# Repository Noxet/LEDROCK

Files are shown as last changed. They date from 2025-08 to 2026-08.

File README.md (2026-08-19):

# LEDROCK

LEDROCK is a custom controller for the IKEA LEDBERG RGB LED strip, built around an ESP32.

The project replaces the original LEDBERG controller and adds multiple ways of controlling the strip. It can be controlled over Wi-Fi using WebSockets, or directly over a serial connection using a custom command protocol.

A desktop light-bar application can capture the colors along the lower edge of the PC display and reproduce them on the LED strip, turning it into a lightweight screen-reactive ambient lighting system.

The repository contains the complete project, including:

- ESP32 firmware - LED control, WebSocket interface, and serial command protocol
- Custom controller hardware
- Desktop light-bar application - mirrors colors from the lower portion of the display
- Command-line application - direct control of the LED strip over USB-C

The project combines custom hardware, embedded firmware, networking, serial communication, and desktop software into a complete LED control system.

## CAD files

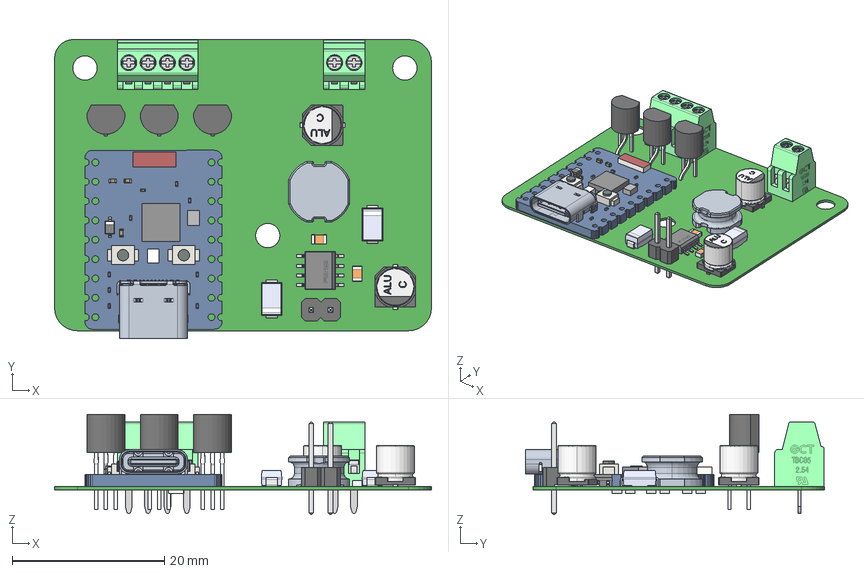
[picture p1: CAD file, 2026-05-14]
hardware/Ledrock/Manufacturing/ExportSTEP/Ledrock.step
49.5 x 39.3 x 13.2 mm
User Library-DO-214AC_SMA x 2
BOARD
USER_LIBRARY-RES_0603-0201_1 x 9
USER_LIBRARY-RES_0603-0201_2 x 9
USER_LIBRARY-RES_0603-0201_3 x 9
USER_LIBRARY-RES_0603-0201_4 x 9
EXTRUDED-29178
2_A x 13
EXTRUDED-51780
EXTRUDED-52493 x 2
SOD323
3_1_A x 3
CORE
CA-C03
User Library-TPS54360DDA
User Library-R_0805 x 6
User Library-Pin Header Strip
srn8040-150m
Fuss_1 x 2
Pins_1 x 2
Korper_1 x 2
Beschriftnug_1 x 2
User Library-C0805-2 x 2

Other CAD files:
hardware/Ledrock/Manufacturing/AutoCAD PCB/Ledrock.DXF
hardware/Ledrock/Manufacturing/AutoCAD PCB/Ledrock.DWG

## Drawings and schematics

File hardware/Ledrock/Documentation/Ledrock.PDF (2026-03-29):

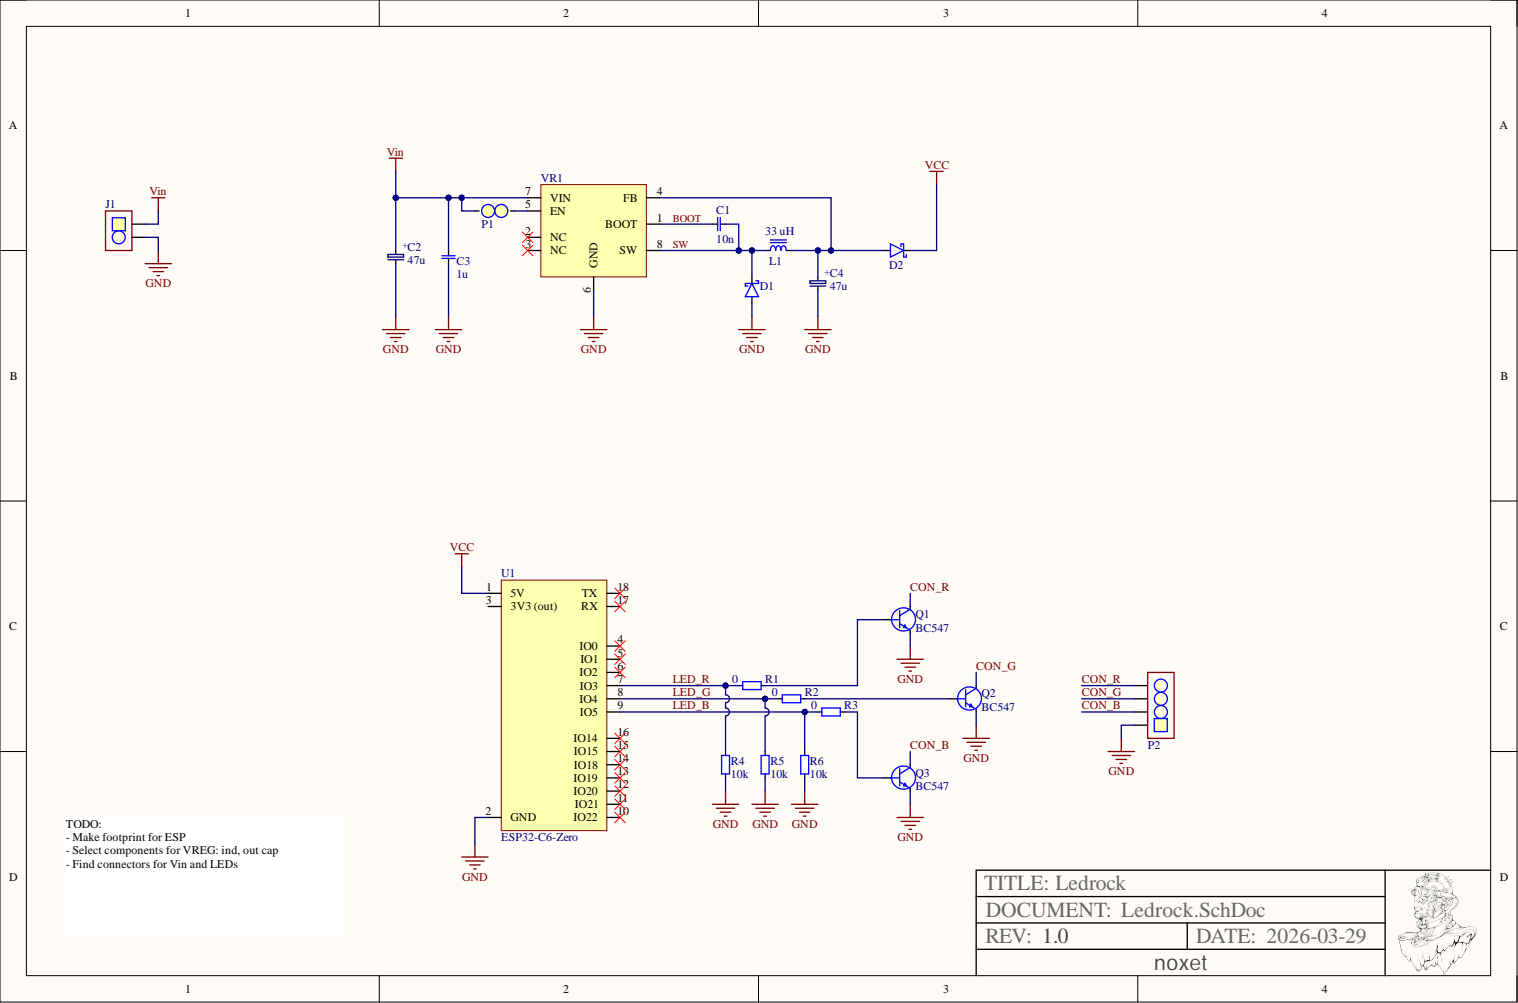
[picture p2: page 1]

TODO:
- Make footprint for ESP
- Select components for VREG: ind, out cap
- Find connectors for Vin and LEDs

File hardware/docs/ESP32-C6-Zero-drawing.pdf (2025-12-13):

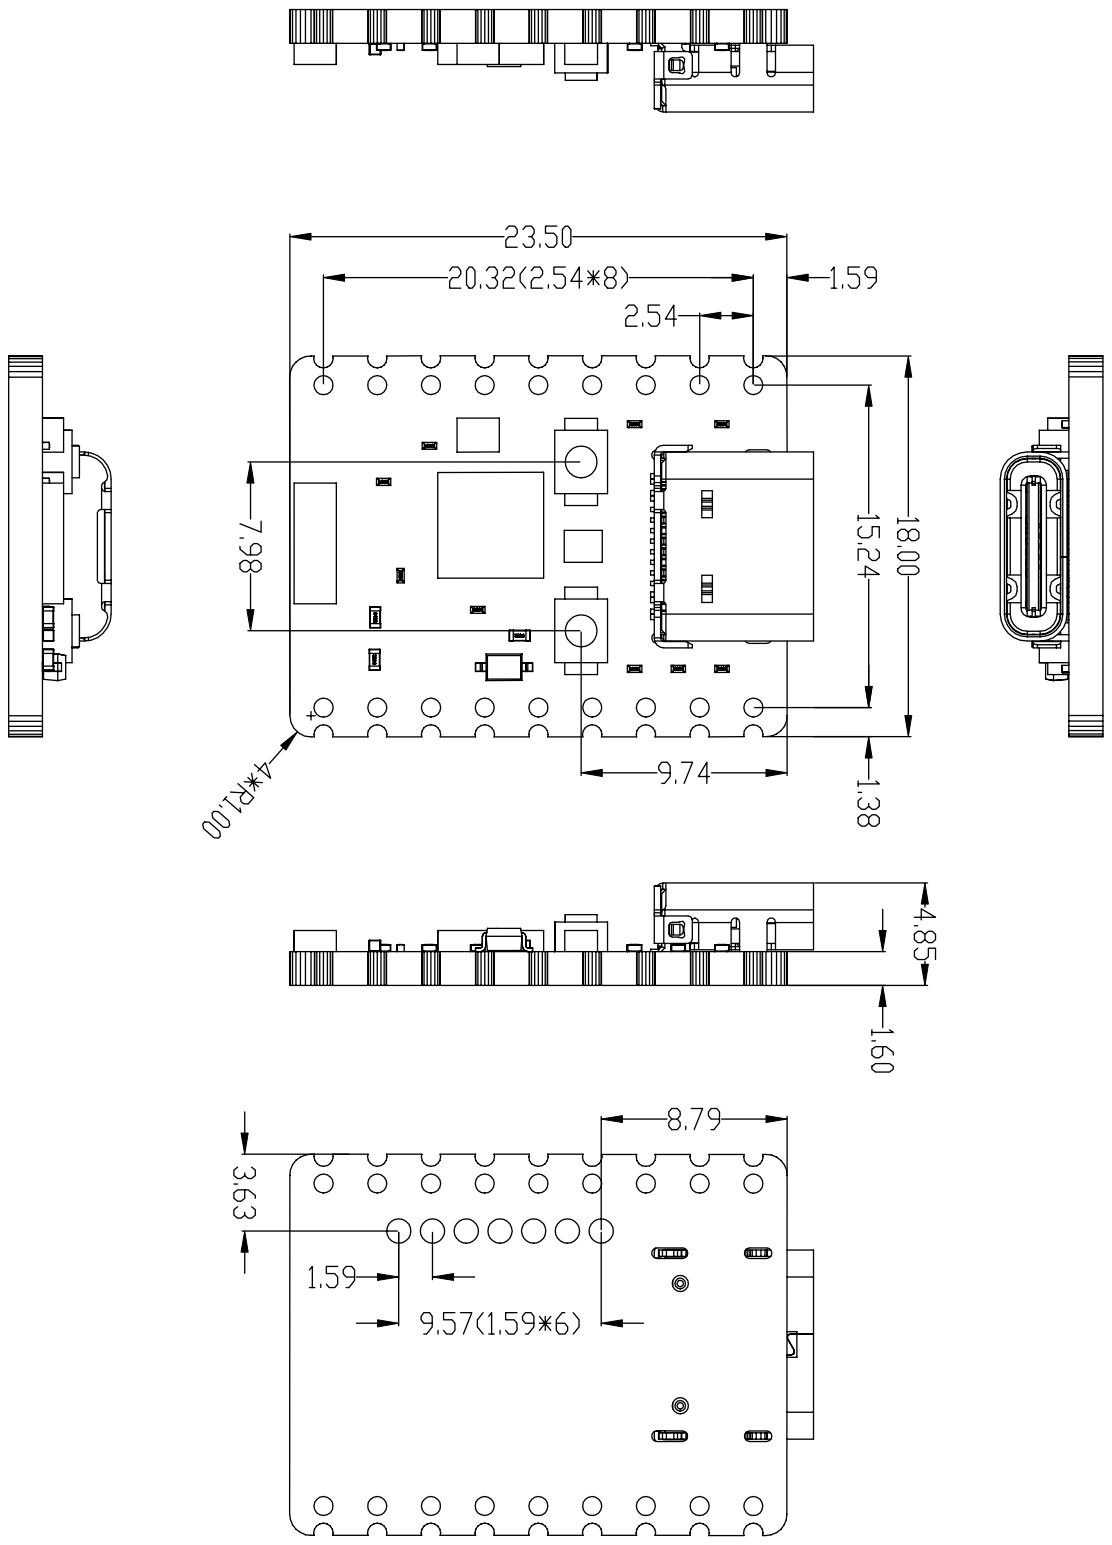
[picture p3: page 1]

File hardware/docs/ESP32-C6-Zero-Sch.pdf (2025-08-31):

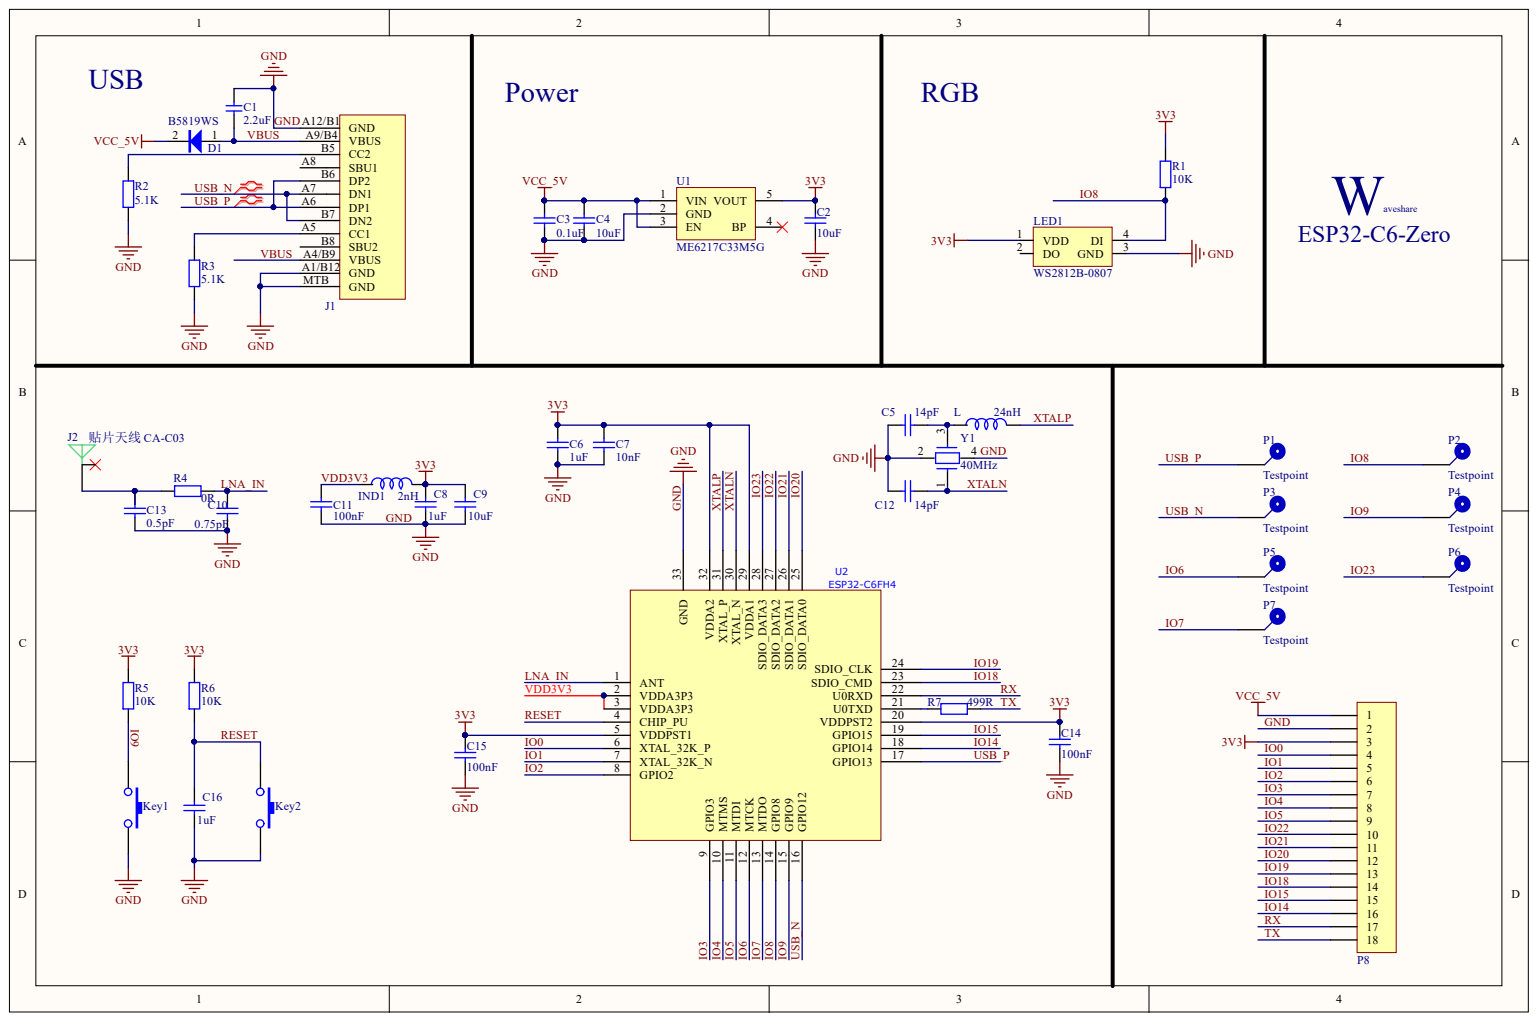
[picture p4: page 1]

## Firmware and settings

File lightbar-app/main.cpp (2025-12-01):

#include <Windows.h>
#include <dxgi1_2.h>
#include <d3d11.h>
#include <wrl.h>
#include <iostream>
#include <cstdint>

using Microsoft::WRL::ComPtr;

HANDLE serialOpen(const std::string &port, DWORD baud = CBR_115200)
{
	HANDLE handle = CreateFileA(
	    port.c_str(),
	    GENERIC_READ | GENERIC_WRITE,
	    0,
	    nullptr,
	    OPEN_EXISTING,
	    FILE_ATTRIBUTE_NORMAL,
	    nullptr
	    );

	if (handle == INVALID_HANDLE_VALUE)
	{
		std::cerr << "Failed to open " << port << "\n";
		return nullptr;
	}

	DCB dcb = { 0 };
	dcb.DCBlength = sizeof(dcb);

	if (!GetCommState(handle, &dcb)) {
		std::cerr << "GetCommState failed\n";
		CloseHandle(handle);
		return nullptr;
	}

	dcb.BaudRate = baud;
	dcb.ByteSize = 8;
	dcb.StopBits = ONESTOPBIT;
	dcb.Parity   = NOPARITY;
	dcb.fDtrControl = DTR_CONTROL_ENABLE;

	if (!SetCommState(handle, &dcb)) {
		std::cerr << "SetCommState failed\n";
		CloseHandle(handle);
		return nullptr;
	}

	// Timeout settings (non-blocking)
	/*
	COMMTIMEOUTS timeouts = { 0 };
	timeouts.ReadIntervalTimeout = 50;
	timeouts.ReadTotalTimeoutConstant = 50;
	timeouts.ReadTotalTimeoutMultiplier = 10;
	timeouts.WriteTotalTimeoutConstant = 10;
	 */

	//SetCommTimeouts(handle, &timeouts);

	return handle;
}

bool serialWrite(HANDLE handle, const uint8_t *data, int len)
{
	DWORD written;
	uint8_t msg[5];
	msg[0] = 0x04;
	msg[1] = 0x01; // static color
	memcpy(&msg[2], data, 3);
	// clean any leftover data in the software buffer. The latest data is more important
	PurgeComm(handle, PURGE_TXCLEAR);
	FlushFileBuffers(handle);
	if (!WriteFile(handle, msg, sizeof(msg), &written, nullptr)) return false;
	return written == sizeof(msg);
}

int main()
{
	HANDLE serial = serialOpen(R"(\\.\COM10)");
	if (!serial)
	{
		std::cerr << "Failed to open serial port\n";
		return EXIT_FAILURE;
	}

	HRESULT hr;

	// Create D3D11 device
	ComPtr<ID3D11Device> device;
	ComPtr<ID3D11DeviceContext> ctx;

	hr = D3D11CreateDevice(
	    nullptr,
	    D3D_DRIVER_TYPE_HARDWARE,
	    nullptr,
	    D3D11_CREATE_DEVICE_BGRA_SUPPORT,
	    nullptr, 0,
	    D3D11_SDK_VERSION,
	    &device,
	    nullptr,
	    &ctx);

	if (FAILED(hr)) {
		std::cout << "D3D11CreateDevice failed\n";
		return -1;
	}

	ComPtr<IDXGIDevice> dxgiDevice;
	device.As(&dxgiDevice);

	// Get primary output
	ComPtr<IDXGIAdapter> adapter;
	dxgiDevice->GetAdapter(&adapter);

	ComPtr<IDXGIOutput> output;
	adapter->EnumOutputs(0, &output);

	ComPtr<IDXGIOutput1> output1;
	output.As(&output1);

	// Create duplication
	ComPtr<IDXGIOutputDuplication> dup;
	hr = output1->DuplicateOutput(device.Get(), &dup);
	if (FAILED(hr)) {
		std::cout << "DuplicateOutput failed\n";
		return -2;
	}

	DXGI_OUTDUPL_DESC desc;
	dup->GetDesc(&desc);

	UINT W = desc.ModeDesc.Width;
	UINT H = desc.ModeDesc.Height;

	// We only want bottom N rows:
	const UINT NUM_ROWS = 300;

	// Create staging texture for bottom rows only
	D3D11_TEXTURE2D_DESC stagingDesc = {};
	stagingDesc.Width = W;
	stagingDesc.Height = NUM_ROWS;
	stagingDesc.MipLevels = 1;
	stagingDesc.ArraySize = 1;
	stagingDesc.Format = DXGI_FORMAT_B8G8R8A8_UNORM;
	stagingDesc.SampleDesc.Count = 1;
	stagingDesc.Usage = D3D11_USAGE_STAGING;
	stagingDesc.CPUAccessFlags = D3D11_CPU_ACCESS_READ;

	ComPtr<ID3D11Texture2D> staging;
	device->CreateTexture2D(&stagingDesc, nullptr, &staging);

	// Capture loop
	while (true)
	{
		DXGI_OUTDUPL_FRAME_INFO info = {};
		ComPtr<IDXGIResource> frameRes;

		hr = dup->AcquireNextFrame(5, &info, &frameRes);
		if (hr == DXGI_ERROR_WAIT_TIMEOUT)
			continue;
		if (FAILED(hr))
			break;

		ComPtr<ID3D11Texture2D> frameTex;
		frameRes.As(&frameTex);

		// Copy only bottom rows into staging tex
		D3D11_BOX srcBox = {};
		srcBox.left = 0;
		srcBox.right = W;
		srcBox.top = H - NUM_ROWS;
		srcBox.bottom = H;
		srcBox.front = 0;
		srcBox.back  = 1;

		ctx->CopySubresourceRegion(
		    staging.Get(),
		    0,
		    0, 0, 0,
		    frameTex.Get(),
		    0,
		    &srcBox);

		// Map only the small region
		D3D11_MAPPED_SUBRESOURCE map;
		hr = ctx->Map(staging.Get(), 0, D3D11_MAP_READ, 0, &map);

		if (SUCCEEDED(hr)) {
			uint8_t* row = (uint8_t*)map.pData;

			uint64_t sumR = 0, sumG = 0, sumB = 0;
			uint64_t count = uint64_t(W) * NUM_ROWS;

			for (UINT y = 0; y < NUM_ROWS; y++)
			{
				uint8_t* pix = row;
				for (UINT x = 0; x < W; x++)
				{
					uint8_t B = pix[0];
					uint8_t G = pix[1];
					uint8_t R = pix[2];

					sumR += R;
					sumG += G;
					sumB += B;

					pix += 4;
				}
				row += map.RowPitch;
			}

			uint8_t avgR = uint8_t(sumR / count);
			uint8_t avgG = uint8_t(sumG / count);
			uint8_t avgB = uint8_t(sumB / count);

			// Print or send to LED strip:
			std::cout << "AVG RGB = "
			          << (int)avgR << ", "
			          << (int)avgG << ", "
			          << (int)avgB << "\n";
			uint8_t pkt[] = { avgR, avgG, avgB };
			serialWrite(serial, pkt, sizeof(pkt));

			ctx->Unmap(staging.Get(), 0);
			Sleep(10);
		}

		dup->ReleaseFrame();
	}

	return EXIT_SUCCESS;
}

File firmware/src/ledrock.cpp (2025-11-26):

#include "core/log.h"
#include "core/sys.h"
#include "driver/gpio.h"
#include "drivers/ledstrip.h"
#include "http_server.h"
#include "led_controller.h"
#include "uart_cli.h"
#include "http_server.cpp"
#include "core/log.h"

#include "esp_log.h"
#include "esp_log_level.h"
#include "hal/gpio_types.h"
#include "freertos/FreeRTOS.h"
#include "freertos/task.h"
#include "portmacro.h"

#include <cstdio>


extern "C" void app_main(void)
{
    sys_init();

    LRLOGI("Booting up, post HTTP and LRLog init\n");

    Ledstrip leds;
    LedController lc{leds};
    xTaskCreate(&LedController::ledControllerTask, "lc task", 4096, &lc, 10, nullptr);

    UartCLI cli{lc.getQueue()};

    HTTPServer httpServer{lc.getQueue()};
    xTaskCreate(&HTTPServer::httpServerTask, "http task", 4096, &httpServer, 5, nullptr);

    LRLog::instance().init(httpServer.getQueue());

    while (1)
    {
        //gpio_set_level(LEDPIN, 1);
        cli.poll();
        vTaskDelay(10 / portTICK_PERIOD_MS);
        //gpio_set_level(LEDPIN, 0);
        //vTaskDelay(1000 / portTICK_PERIOD_MS);
    }
    printf("Restarting now.\n");
    fflush(stdout);
    esp_restart();
}

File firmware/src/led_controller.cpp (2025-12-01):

#include "led_controller.h"
#include "core/log.h"
#include "core/sys.h"
#include "message.h"
#include "core/color.h"

#include "FreeRTOSConfig.h"
#include "esp_log.h"
#include "freertos/FreeRTOS.h"
#include "freertos/idf_additions.h"
#include "freertos/projdefs.h"
#include "freertos/task.h"
#include "portmacro.h"
#include <cstdint>
#include <cstring>
#include <optional>
#include <string>


static const char *TAG = "LED_CTRL";


enum class LCSTATE
{
    IDLE,
    PULSE,
    CLEAR,
};

static void updateState(LCSTATE &state, const LCSTATE &newState);
static constexpr const char *eventToString(const Event &ev);


LedController::LedController(ILedDriver &driver)
    : m_driver(driver)
{
    m_queue = xQueueCreate(10, sizeof(Event));
}


void LedController::init()
{
    m_driver.init();
}


void LedController::run()
{
    LCSTATE state = LCSTATE::IDLE;
    std::optional<Event> current;
    while (1)
    {
        // fetch event if we are not currently handling one.
        if (!current && state == LCSTATE::IDLE)
        {
            Event tmp;
            if (xQueueReceive(m_queue, &tmp, 0) == pdPASS)
            {
                current = std::move(tmp);
                if (current) LRLOGI("Got new event: %s\n", eventToString(current.value()));
            }
        }

        switch (state)
        {
            case LCSTATE::IDLE:
            {
                if (!current) break;

                const auto &ev = current.value();
                switch(ev.type)
                {
                    case MsgType::STATIC:
                        if (setStaticColor(ev.data.staticColor.color))
                        {
                            // const auto &c = ev.data.staticColor.color;
                            // LRLOGI("Static color set: %s", Color::toString(c).c_str());
                            ESP_LOGI(TAG, "Set staticcolor done");
                            current.reset();
                        }
                        break;

                    case MsgType::FADE:
                        if (setFadeColor(ev.data.fadeColor.from, ev.data.fadeColor.to, ev.data.fadeColor.time))
                        {
                            ESP_LOGI(TAG, "Set fadecolor done");
                            current.reset();
                        }
                        break;

                    case MsgType::PULSE:
                        if (setPulseColor(ev.data.fadeColor.from, ev.data.fadeColor.to, ev.data.fadeColor.time, true))
                        {
                            // do not reset current event here since we need its data in PULSE state.
                            ESP_LOGI(TAG, "Set pulsecolor done");
                            updateState(state, LCSTATE::PULSE);
                        }
                        break;

                    case MsgType::NONE:
                    default:
                        current.reset();
                        break;
                }
            } break;

            case LCSTATE::PULSE:
            {
                // we need a valid event while pulsing
                configASSERT(current.has_value());
                const auto &ev = current.value();

                Event tmp;
                if (xQueueReceive(m_queue, &tmp, 0) == pdPASS)
                {
                    // Preempt if a new state has arrived, so we don't have to wait for fading to finish.
                    current = std::move(tmp);
                    if (current) ESP_LOGI(TAG, "Got new event: %s", eventToString(current.value()));
                    updateState(state, LCSTATE::IDLE);
                    break;
                }

                if (setPulseColor(ev.data.fadeColor.from, ev.data.fadeColor.to, ev.data.fadeColor.time, false))
                {
                }
            } break;

            case LCSTATE::CLEAR:
                if (setStaticColor(Color{"000000"}))
                {
                    updateState(state, LCSTATE::IDLE);
                }
                break;
        }

        // pet the dog
        vTaskDelay(pdMS_TO_TICKS(10));
    }
}


QueueHandle_t LedController::getQueue()
{
    return m_queue;
}


bool LedController::setStaticColor(const Color &color)
{
    // printf("[%lld] set static\n", getUptime());
    bool ret = m_driver.setStaticColor(color);
    return ret;
    // printf("[%lld] static done\n", getUptime());
}


bool LedController::setFadeColor(const Color &from, const Color &to, uint32_t time)
{
    // printf("[%lld] set fade\n", getUptime());
    setStaticColor(from);
    vTaskDelay(20 / portTICK_PERIOD_MS);
    bool ret = m_driver.setFadeColor(from, to, time);
    return ret;
    // printf("[%lld] fade done\n", getUptime());
}

bool LedController::setPulseColor(const Color &from, const Color &to, uint32_t time, bool reset)
{
    static Color _from = from;
    static Color _to = to;
    if (reset)
    {
        _from = from;
        _to = to;
    }

    bool ret = setFadeColor(_from, _to, time);

    // swap so we can fade the other way the next time the function is called.
    Color tmp = _from;
    _from = _to;
    _to = tmp;
    return ret;
}


/**
 * Just grab the led controller from the passed param, and run the inf loop
 */
void LedController::ledControllerTask(void *pvParam)
{
    // TODO: Add logging over wifi, and abort
    assert(pvParam);
    LedController *lc = static_cast<LedController *>(pvParam);
    lc->init();
    lc->run();
}


static constexpr const char *stateToString(const LCSTATE &state)
{
    switch (state)
    {
        case LCSTATE::IDLE: return "IDLE";
        case LCSTATE::PULSE: return "PULSE";
        case LCSTATE::CLEAR: return "CLEAR";
    }

    return "UNKNOWN STATE";
}


static constexpr const char *eventToString(const Event &ev)
{
    switch (ev.type)
    {
        case MsgType::STATIC: return "STATIC";
        case MsgType::FADE: return "FADE";
        case MsgType::PULSE: return "PULSE";
        case MsgType::NONE: return "NONE";
    }

    return "UNKNOWN EVENT";
}


static void updateState(LCSTATE &state, const LCSTATE &newState)
{
    ESP_LOGI(TAG, "[%s]->[%s]", stateToString(state), stateToString(newState));
    state = newState;
}

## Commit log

2021-01-31 Added initial example code for testing PWM
2021-02-03 Do not track vscode folder
2021-02-03 Test simple PWM
2021-02-20 Use HW fading with interrupts, wip
2023-01-04 Do not track Visual Studio folder
2023-01-06 Initialize struct in correct order
    [ledrock.cpp]
2023-01-06 Added input interrupt for button
2023-01-06 Fixed interrupt bug
2023-01-07 Added an event cast function to safely convert to correct subtypes
    [ledrock.cpp]
2023-01-08 Added timer events
2023-01-08 Added timer interrupt and generate timer events, wip
2023-01-08 Added IRAM ATTR to timer isr handler, and added extern C
2023-01-08 Added onEvent in color manager, to handle and distribute all events. Added switching color mode.
2023-01-08 #3 - Added timer class, refactored switch color to take timer as argument. TODO, make sure we can create multiple timers, corresponding to the HW timers
2023-02-13 Added led fade event, wip
2023-02-17 Added debounce timer, refactored timer class
2023-02-18 Refactoring, making LED a semi-singleton, wip
2023-02-18 Got fade callback working, issue with blocking calls somewhere, wip
    [ledrock.cpp]
2023-02-19 Added global counter to keep track of all fade events
2025-05-11 Refactored, added led driver interface
2025-08-31 Started hw project
    [Ledrock.PrjPcb, Ledrock.SchDoc, Ledrock.SchLib]
2025-08-31 Added ESP board schematic
2025-09-01 Migrated to ESP32-C6, added UART CLI interface
2025-09-02 Uart CLI is working, added some testing code
2025-09-02 Do not track local clangd config
2025-09-04 #8 - Fixed blocking calls for ledstrip, by checking value of semaphore
    [led_controller.cpp, ledrock.cpp, ledstrip.cpp]
2025-09-04 #8 - Fixed delay in handling messages from queue. Keep the dog happy too
    [led_controller.cpp, ledrock.cpp, uart_cli.cpp]
2025-09-08 Do not track zig bins and cache
2025-09-09 FSM now working properly for led controller.
2025-09-09 #10 - Added log class to print logs to UART, wip
2025-09-10 #10 - Improved logging for UART. Fixed some logging TAGs
    [led_controller.cpp, ledrock.cpp, uart_cli.cpp]
2025-09-10 cli app seems to work for all current modes, todo: fix hardcoded time
2025-09-16 Do not track autogenerated stuff
2025-10-20 Added components to schematic. Added ESP32 footprint
    [Ledrock.PcbLib, Ledrock.PrjPcb, Ledrock.SchDoc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]
2025-10-27 Replaces wifi module with http ws.
    [ledrock.cpp]
2025-11-16 Logger works, prints to websocket and uart. TODO: WS timing is a bit slow
2025-11-22 Added a getter to the queue handle of led controller
2025-11-26 Setting static color over WS works. Fixed minor bugs
    [led_controller.cpp, ledrock.cpp]
2025-12-01 Updated UART protocol
2025-12-01 Do not track CLion stuff
2025-12-01 Updated UART protocol to include data length. Handle unknown cases in LC
2025-12-05 Added PPK2 current measurement
2025-12-05 Added voltage regulator component, wip
    [Ledrock.SchDoc]
2025-12-06 Added components to vreg
    [Ledrock.PcbDoc, Ledrock.PrjPcb, Ledrock.SchDoc]
2025-12-11 Finished DCDC schematic, added connectors for power and LEDs
    [Ledrock.SchDoc]
2025-12-13 Migrated to separate library in project
    [Ledrock.PcbLib, Ledrock.SchLib]
2025-12-13 Added ESP32 drawing
2025-12-13 Started PCB layout, wip
    [Ledrock.PcbDoc, Ledrock.PrjPcb, Ledrock.SchDoc]
2025-12-15 Do not track Altium logs
2025-12-15 Did PCB layout
    [Ledrock.PcbDoc, Ledrock.SchDoc]
2026-03-29 Added protection diode, ordered from JLC
    [Ledrock.GBL, Ledrock.GBO, Ledrock.GBP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]
2026-04-19 Fixed Pad connection on vreg
    [Ledrock.SchDoc]
2026-04-19 Fixed 4 pole connector, replaced gnd with 24V. made smaller pads for ESP32
    [Ledrock.PcbLib, Ledrock.PrjPcb, Ledrock.SchDoc]
2026-05-14 Updated job file, exporting STEP and DXF
    [Ledrock.DWG, Ledrock.DXF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]
